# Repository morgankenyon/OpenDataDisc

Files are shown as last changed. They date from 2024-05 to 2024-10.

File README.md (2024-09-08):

# OpenDataDisc

An open platform that allows disc golfers to collect their throw statistics.

> Your throw, your data, your platform.

## Pics

> Putter Dev Board
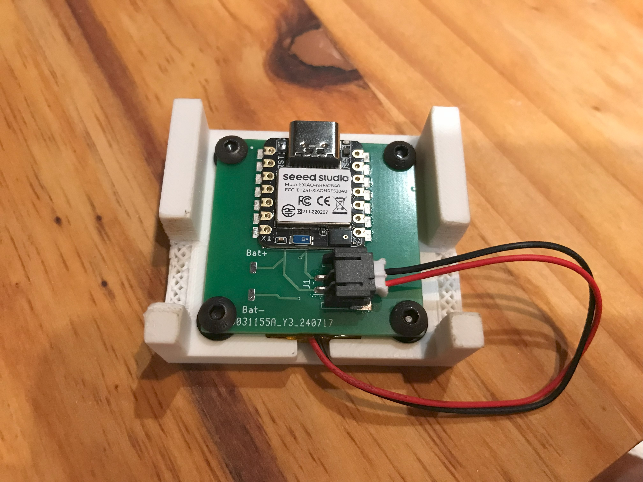
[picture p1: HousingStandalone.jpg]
OpenDataDisc Housing


> Putter Board Mounted On Disc
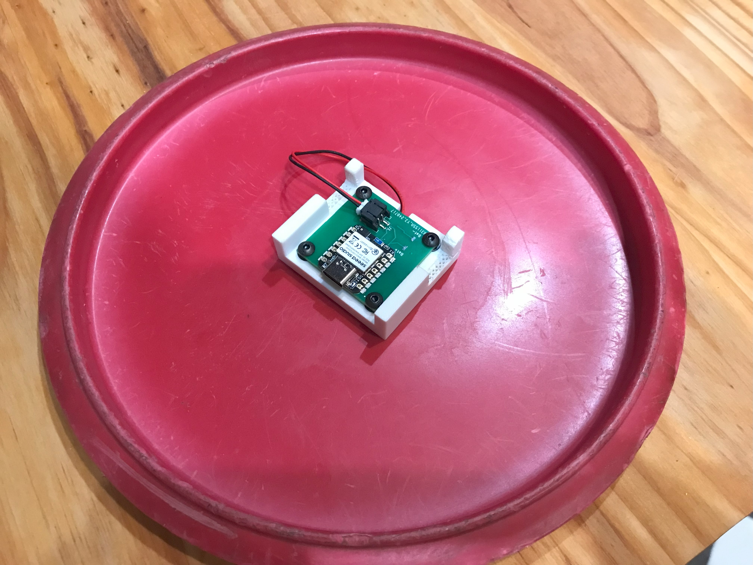
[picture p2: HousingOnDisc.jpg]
OpenDataDisc On Disc


I'm documentating my process over on my [youtube channel](https://www.youtube.com/@BlenderDiscGolf).

## Disc Golf + Analytics

I'd love the ablity to track and measure my disc golf throws without spending tons of money.

* Would it be easier to buy one of the currently available products? Probably.
* What's the likelihood this project never completes its goal? Higher than 0.

So why I am doing it? I'm a sucker for starting something new, I'm a software developer, have started playing disc golf and wanted a project to combine those 2.

Will that mix actually produce something usable? No idea.

## Current Project Phase

Phase: Putter version

As shown in the pics above, I have a putter dev board that I'm just starting to use to measure statistics of putts.

Putts are easier to measure due to low speeds and rpms.

## Project Phases (Somewhat flexible now)

* Getting to know hardware
  * Buying the hardware I think I need.
  * Hooking everything up.
  * Getting data flowing between microcontroller and computer.
  * Getting some basic calculations working
* Putter version (current phase)
  * Putts have slow RPMs and low Gs
    * These values are much easier to measure and test.
    * Hardware is also cheaper.
    * Will probably be using as many off the shelf parts as possible. (Nothing really custom designed)
  * Create a developer kit that can be used for putters.
    * Not something that would probably be widely available, but might create some dev kits for technical people wanting to help.
  * Need some hardware to confirm the sensor values.
    * Speed gun, high speed camera, etc
  * Most R&D on this project will be based on this platform.
* Alpha Driver Disc
  * To develop something to track high speed throws, will probably need:
    * Custom hardware
    * Beefed up software
    * More expensive testing equipment
* Beta Driver Disc
  * Create a more refined alpha setup
  * Any problems I encountered in the Alpha disc can be changed here
* Driver Disc
  * First proper product release
  * Should be easy for non technical people to setup and use
  * Lots of polish will need to happen before this is ready

## Repo Layout

This repo holds both [hardware](./hardware/README.md) and [software](./software/README.md) for the OpenDataDisc project. As this project is still in it's early phase, there's no instructions on how to build your own and run on your own computers. 

That information will come as the project progresses.

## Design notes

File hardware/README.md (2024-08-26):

# OpenDataDisc Hardware

Current status: Attempting to build a putter version. Something that can track low G and low rotation throws.

## Hardware Components

Currently I'm using the following:
* Brains - a [Xiao NRF52 Sense](https://www.seeedstudio.com/Seeed-XIAO-BLE-Sense-nRF52840-p-5253.html)
  * Earlier I used an esp32 microcontroller, but since I didn't need wifi moved to something that fit my requirements and will have longer battery life.
  * This board includes an IMU, USB and LiIon charging circuits built in
* Power - exploring this [110 mAh LiIon battery](https://www.mouser.com/ProductDetail/SparkFun/PRT-13853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), still in the early phases of testing this.
* Casing - 3d printed housing.
  * Currently the files needed to print yourself one are located in [02_putter_housing](./examples/02_putter_housing/).

## DIY Instructions

TBD - right now nothing is integrated. Further instructions will follow as project progresses.

## Examples

The example folder currently contains work that in progress. As hardware designs finalize and are ready for other people to use/build themselves. They will get promoted from the examples folder to this folder.

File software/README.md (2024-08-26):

# OpenDataDisc Software

This folder holds all relevant software for the OpenDataDisc project. Software is split into 2 different sub projects:

* client - .NET based project that runs on a Windows PC. Receives telemetry about the disc from the microcontroller and displays it to the user.
* microcontroller - attached to the disc and is responsible for gathering data about the discs acceleration and movement. Sends that information to the client.

## Current Architectural Guidelines

* Have microcontroller code be as simple as possible.
  * Professionally I'm a .NET developer, I'm more comfortable programming in C#. 
  * I don't want the microcontroller code to get too complex.
* Microcontroller sends raw data to the client
  * Currently the microcontroller does not do any calculations of it's own.
  * It sends pulls in data from sensors and sends to client.
* Client handles all complex calculations
  * Any calculations needed for throws happens on the client.

## How to Run

TBD

Right now the limiting factor in trying this yourself is hardware. I'm still building out a putter version, so until that's at a point where people can copy it there's really no sense it getting this running.

## Examples

In the examples folder are numerous attempts I had to get certain portions of this project running individually. (Can I connect to bluetooth, can I read accelerometer values, can I create a simple Avalonia application). There's not much value in them now.

Our current `/client` and `/microcontroller` code started as examples and were promoted as they became ready.

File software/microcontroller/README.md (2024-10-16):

# Microcontroller

This project uses a [XIAO nRF52840 Sense](https://www.seeedstudio.com/Seeed-XIAO-BLE-Sense-nRF52840-p-5253.html) as the brains.

It's main purpose is to establish a bluetooth connection between itself and the client, then send over accelerometer and gyro sensor readings.

## Local Project Setup

* Install nRF Connect locally
  * Here is a YouTube playlist demonstrating how to do that.
  * https://www.youtube.com/watch?v=EAJdOqsL9m8&list=PLx_tBuQ_KSqEt7NK-H7Lu78lT2OijwIMl
  * I installed the latest versoin at the time (v2.7.0)
* Create build folder
  * By default, the `/build` folder of an nRF Connect project is not checked into git.
    * This is the default right now, not sure if it should change?
  * Using the nRF Connect Plugin, add a new build configuration, target the proper board.
  * nRF 52840 Dev Kit:
  targetting dev kit
    * I used this board during early development
  * XIAO nRF52840 Sense:
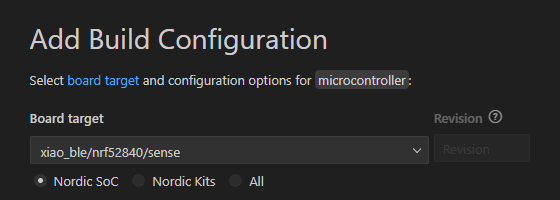
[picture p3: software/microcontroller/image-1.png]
targetting Xiao Sense board
  
  * Just accept the defaults for everything else.
* Build and flash using the plugin
  * Using the nRF Connect Plugin, build and flash the application.
  * You can use the "Connected Devices" area to view the serial monitor if needed.

## Issues and TODOs

None at the moment

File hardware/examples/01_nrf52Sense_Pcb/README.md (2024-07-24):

# NRF52 Sense PCB Design

After watching [this youtube video](https://www.youtube.com/watch?v=2vHB8AUQKWM), it made the point that if I am not planning on using Wifi, the esp32 is a bit overkill. I can reduce my power/battery requirements by picking another board.

So I landed on the NRF52 microcontroller. I specifically have bought a [Seeed Studio XIAO nRF52840 (Sense)](https://wiki.seeedstudio.com/XIAO_BLE/).

This experiment is an attempt to design a PCB that I can attach the dev board to, to one day put it on a disc.

Using a M3 mouting hole on the PCB. Based on Reddit below.

M3 screws have a Major Diameter of 3.0 mm, I made the mounting holes on my PCB 3.1 mm.

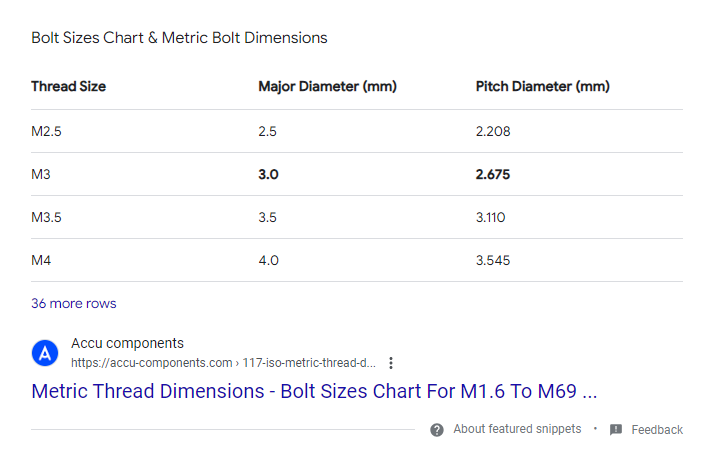
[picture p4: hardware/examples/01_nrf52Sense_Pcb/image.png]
screw mounting sizes


## Resources

* Mounting hole diameter - https://www.reddit.com/r/AskElectronics/comments/uet1u9/comment/i6qwwx0/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
* Generating Gerber Files from Kica - https://www.pcbway.com/helpcenter/technical_support/Generate_Gerber_file_from_Kicad.html

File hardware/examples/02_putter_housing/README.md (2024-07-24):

# Putter Housing (3d Print)

After creating the PCB in example 1, I needed a housing to assemble everything together.

## Tinkercad Design

I have designed the following 3d printed housing:

Tinkercad link: https://www.tinkercad.com/things/eYMJKqX6BG7-incredible-lappi/edit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

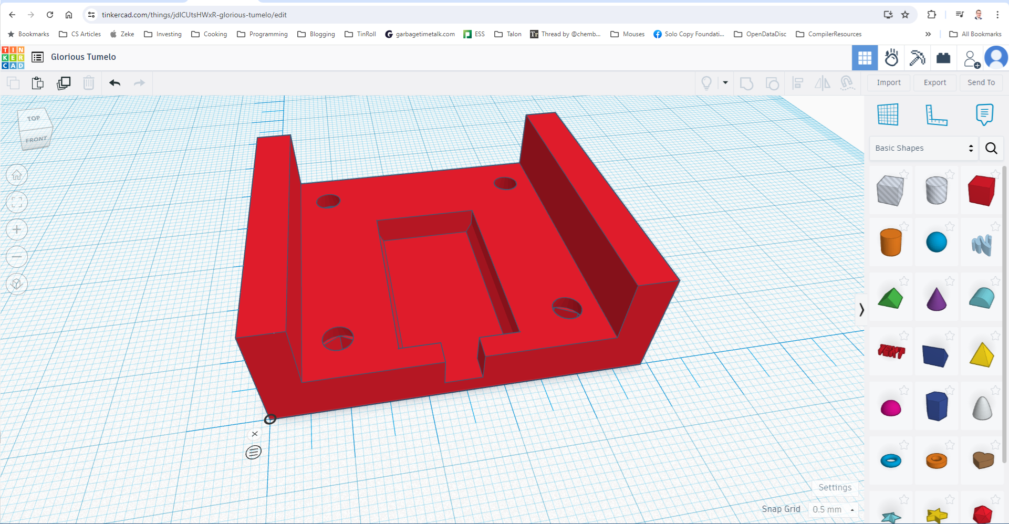
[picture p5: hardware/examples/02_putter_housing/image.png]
putter 3d design


It has 4 screw holes to attach the PCB, a well for the battery and 2 spacers to ensure nothing damages the circuit board.

The 3d design is contained in the [Putter Housing v2.zip](./Putter%20Housing%20v2.zip) file for anyone interested in making their own.

## Resources

* Metric Nut Dimensions - https://amesweb.info/Fasteners/Nut/Metric-Hex-Nut-Sizes-Dimensions-Chart.aspx
* M3 screw kit I bought - https://www.amazon.com/gp/product/B0C8HV5C3N/ref=ppx_yo_dt_b_asin_title_o00_s00?ie=UTF8&psc=1

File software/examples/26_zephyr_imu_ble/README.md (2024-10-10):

# Sending IMU Data Over Bluetooth

In my previous example I was able to pull both the Accelerometer and Gyro data at once.

Now I want to write code that will allow me to send that data over bluetooth to my host machine.

I'll basically be combining code from example 25 and example2/ble_test.

## My goals

1. Send IMU data over to my host machine
2. Allow writing of more than 23 bytes (by default a BLE notify message is limited to 23 bytes)
3. Save the IMU data into the SQLite database.

Todo:
* Determine how to check if bluetooth device is connected before trying to send any notify messages

The new config lines I added to bump up the bluetooth message size.
```
CONFIG_BT_BUF_ACL_RX_SIZE=502
CONFIG_BT_L2CAP_TX_MTU=498
```
## Accomplishment

I'm able to send over about 60 bytes in one bluetooth message, then my C# client can parse that and store it in my SQLite database!!

Let's go!

## Issues

* Building C strings in zephyr
  * https://stackoverflow.com/questions/76546266/float-to-string-in-c-using-nrf-mcu-and-zephyr
* Upping bluetooth byte in zephyr
  * https://devzone.nordicsemi.com/f/nordic-q-a/81860/set-mtu-size-in-zephyr/340755
  * https://lists.zephyrproject.org/g/users/topic/sending_notification_with_mtu/16761407

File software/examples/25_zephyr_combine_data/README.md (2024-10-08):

# Combining Sensor Data

In my previous example I was able to get both the Accelerometer and Gyro data. I made one call to the registers for each data type, 1 for acc and 1 for gyro.

Instead I want to make 1 call and get back all data points.

LSM6DS3 Data Sheet - https://content.arduino.cc/assets/st_imu_lsm6ds3_datasheet.pdf

## My goals

1. Load all data necessary from sensor in one call to the IMU
2. Print that information to the screen.

## Accomplishment

I was able to get both data sets in one interaction with the IMU
```
56000: Acc - X: -0.004514, Y: -0.087108, Z: 0.979538
56000: Gyro - X: 2.598750, Y: -3.508750, Z: -3.710000
56500: Acc - X: -0.048068, Y: -0.032452, Z: 1.012478
56500: Gyro - X: 2.432500, Y: -3.815000, Z: -3.963750
57000: Acc - X: -0.050020, Y: -0.049166, Z: 1.023702
57000: Gyro - X: 2.380000, Y: -3.902500, Z: -4.121250
57500: Acc - X: -0.043798, Y: -0.057340, Z: 1.016504
57500: Gyro - X: 2.572500, Y: -3.876250, Z: -3.902500
58000: Acc - X: -0.007808, Y: -0.050752, Z: 0.982954
58000: Gyro - X: 2.546250, Y: -3.850000, Z: -3.718750
```

## Wiring

Same setup as before, connecting SA0 to ground to have address 0x6A.

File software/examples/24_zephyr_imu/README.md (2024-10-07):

# Zephyr & IMU

After using the temperature sensor, now I want to try to use the Accelerometer and Gyro sensors.

Using this library as a starting point and reference: https://github.com/Seeed-Studio/Seeed_Arduino_LSM6DS3

LSM6DS3 Data Sheet - https://content.arduino.cc/assets/st_imu_lsm6ds3_datasheet.pdf

## My goals

1. Allow easy selection and configuration of Accelerometer and Gyro
2. Provide method to pull data from the accelerometer and gyro
3. Print that data to the screen

### Accelerometer Data

The output of the accelerometer data
```
0: X: -0.018666, Y: -0.106994, Z: 0.979538
1: X: -0.037210, Y: -0.066490, Z: 1.007598
2: X: -0.025498, Y: -0.101260, Z: 0.997594
3: X: -0.050630, Y: -0.120048, Z: 0.977586
4: X: -0.031964, Y: -0.065758, Z: 1.005036
```

### Gyro Data

The output of the gyro data

```
0: Gyro - X: 2.310000, Y: -3.990000, Z: -3.780000
1: Gyro - X: 2.450000, Y: -3.710000, Z: -3.920000
2: Gyro - X: 2.520000, Y: -3.850000, Z: -4.200000
3: Gyro - X: 2.520000, Y: -3.850000, Z: -3.850000
4: Gyro - X: 2.520000, Y: -3.850000, Z: -3.990000
5: Gyro - X: 1.960000, Y: -3.850000, Z: -4.130000
6: Gyro - X: 2.380000, Y: -4.340000, Z: -3.850000
7: Gyro - X: 1.820000, Y: -3.990000, Z: -3.850000
8: Gyro - X: 2.310000, Y: -4.200000, Z: -4.060000
9: Gyro - X: 2.240000, Y: -4.060000, Z: -3.920000
```

If I remember correctly I still need to calibrate these values. So this is a stationary and I'll need to average values out so it gets close to zero.

### Combined Data Output

The combined data output:

```
0: Acc - X: -0.053924, Y: -0.034770, Z: 1.000522
0: Gyro - X: 2.485000, Y: -3.701250, Z: -4.331250
1: Acc - X: -0.013298, Y: -0.090524, Z: 0.975634
1: Gyro - X: 2.572500, Y: -3.797500, Z: -3.797500
2: Acc - X: -0.019032, Y: -0.066246, Z: 0.979416
2: Gyro - X: 2.266250, Y: -3.815000, Z: -3.517500
3: Acc - X: -0.049776, Y: -0.045994, Z: 1.015528
3: Gyro - X: 1.863750, Y: -3.543750, Z: -3.482500
4: Acc - X: -0.042822, Y: -0.047214, Z: 1.004792
4: Gyro - X: 2.345000, Y: -3.762500, Z: -3.815000
5: Acc - X: -0.015372, Y: -0.090890, Z: 0.987102
5: Gyro - X: 2.397500, Y: -3.570000, Z: -3.535000
```

## Wiring

Same setup as before, connecting SA0 to ground to have address 0x6A.

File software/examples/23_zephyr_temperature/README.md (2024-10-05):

# Zephyr Temperature Sensor Tests

My Xiao Sense has a LSM6DS3 IMU built into it.

Previously I was using projectIO to interface with my board. Now that I've moved over to Zephyr, it does not have builtin support for the LSM6DS3.

So I'm attempting to write some code to allow me to pull data from my IMU. I'm going to start with reading from the temperature sensor on the IMU.

LSM6DS3 Data Sheet - https://content.arduino.cc/assets/st_imu_lsm6ds3_datasheet.pdf

While I eventually want to use my Xiao Sense with the IMU, right now I am using the nrf52840-dev-kit for this example.

## Wiring Up My Sensor

I'm using the default i2c nodes on the dev board. For the nrf52840-dev-kit, using the device tree viewer that resulted in this configuration:

```javascript
	i2c0_default: i2c0_default {
		group1 {
			psels = <NRF_PSEL(TWIM_SDA, 0, 26)>,
				<NRF_PSEL(TWIM_SCL, 0, 27)>;
		};
	};
```

SDA = 26
SCL = 27
Then GND and 3v3 connections.

I'm also running ground to the SA0 pin, since the SA0 controls what address the device is reachable at.

## Issues

* fatal error: device.h: No such file or directory
  * Changing my import from `#include <device.h>` to `#include <zephyr/device.h>` fixed it for me.
  * Apparently Zephyr changed how their files were referenced lately: https://stackoverflow.com/a/75943320/1352766
* 'i2c0' undeclared here (not in a function)
  * This was received when trying to define the i2c node: `#define I2C_NODE        DT_NODELABEL(i2c0)`
  * Referencing the device tree:
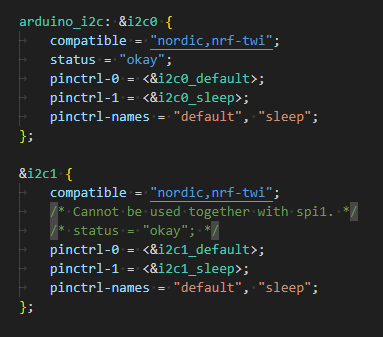
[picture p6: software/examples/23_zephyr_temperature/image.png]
devicetree values

  * `i2c0` didn't seem to be the proper name of that i2c node. I could use either `arduino_i2c` or `i2c1`.
  * Moving to `arduino_i2c` resulted in a successful build for me locally.
* `CONFIG_NEWLIB_LIBC_FLOAT_PRINTF was assigned the value y, but got the value n. Missing dependencies: NEWLIB_LIBC`
  * I removed this from my config file, never really dug into why it was given me an issue
* `i2c_write` fails with a -5 error
  * From this page: https://software-dl.ti.com/simplelink/esd/simplelink_cc13x2_26x2_sdk/5.20.00.52/exports/docs/drivers/doxygen/html/group___i2_c___s_t_a_t_u_s.html
  * -5 = I2C_STATUS_ADDR_NACK (I2C slave address not acknowledged.)
  * confirmed the SA0 pin is connected to ground to try to ensure the i2c device is at memory address 0x6A
  * I probably need to scan through all addresses to see if it shows up anywhere else.
  * Turns out it as at memory address 0x6B for some reason. I'll try to debug further.
memory_addresses
* `read temperature: *float*`
  * Could not print a float out properly.
  * Set this in the `prj.conf` file:
    * `CONFIG_CBPRINTF_FP_SUPPORT=y`
    * It gave this warning though: `Build the cbprintf utility function with support for floating point format specifiers. Selecting this increases stack size requirements slightly, but increases code size significantly.`
  * So apparently enabling float printing has it's drawbacks
  * Since I'm in debug mode it's fine.
* The only temperature value it's printing is 77 F.
  * The IMU might be in test mode.
  * I needed to configure both my Gyro and Accelerometer settings.
  * I did this by writing something to both control registers
    * acc - LSM6DS3_ACC_GYRO_CTRL1_XL
    * gyro - LSM6DS3_ACC_GYRO_CTRL2_G
* Then after that, it started printing out values but was not calibrated.
  * So I had to measure the temperature, compare against an actual temperature gauge, and calculate how many degrees it was off.
  * Mine was off by 16 degrees.
  * The datasheet says the temperature offset would be about +-15 C, which mine is right inline with that.
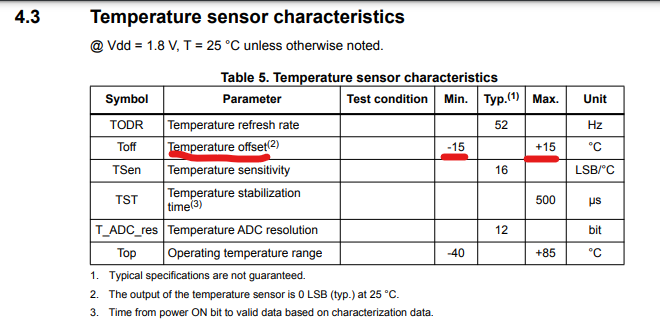
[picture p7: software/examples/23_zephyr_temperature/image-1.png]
temperature data sheet info


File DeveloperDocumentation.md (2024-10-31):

# Developer Documentation

This file contains all technical documentation for this project.

## Microcontroller

TBD

## Avalonia Client

### Database Conventions

* snake_case for all table names, column names and migration names

### Database Migrations

This project uses SQLite to save data coming from disc. The schema of this database is managed by the [DataSchemaService](./software/client/OpenDataDisc.Services/DataSchemaService.cs).

To create a new migration:

* Create a new entry into the `Migration` enum.
  * Ensure it's value is N + 1, where N is the current highest enum value.
* Add a new case statement in `MigrateSchema` method.
* Write SQL statement that will complete the migration
  * Wrap it in a transaction
  * Ensure you insert a new record into the migration table
    * Provide a unique name in snake case (all_lower_text_and_no_spaces)
* Update the class instance variable `_latestMigration` to match your new migration

Expected test cases. 

> In any database PR please indicate whether you've manually performed these steps.

* No SQLite database
  * Ensure on startup a new database is created with all former migrations and your new one.
* Just Your Migration
  * SQLite database with all former migrations.
  * Ensure on startup your migration is added successfully.
* From Latest Release - Future Test Case
  * Start with database from last official release.
  * Ensure on startup that your migration (and any others added since migration) are completed successfully.
* Schema Update Error Rollback
  * Modify your schema update so it fails.
  * Run and see it error out, ensure that the database schema has not been modified at all.
* Migration Tracking Error Rollback
  * Modify your Migration Tracking sql statement so it fails.
  * Run and see it error out, ensure that the database schema has not been modified at all.

Example for last two test cases:

```sql
BEGIN TRANSACTION;

-- Schema Update
CREATE TABLE migrations (name VARCHAR(50), number INT);

-- Migration Tracking
INSERT INTO migrations (name, number) VALUES ('migration_table', 1);

COMMIT;
```

* This migration has 2 logical parts:
  * Schema Update - schema changes to be made
  * Migration Tracking - adding record into migration table indicating migration was run.

* To test the "Schema Update Error Rollback" test case, change your schema so it fails:
  * `CREATEING TABLE migrations (name VARCHAR(50), number INT);`
  * And ensure rollback is successful
* To test the "Migration Tracking Error Rollback" test case, change the statement so it fails:
  * `INSERTING INTO migrations (name, number) VALUES ('migration_table', 1);`

### Icons

The [Avalonia Docs](https://docs.avaloniaui.net/docs/tutorials/music-store-app/add-and-layout-controls#button-icon) detail how to add new icons to the Avalonia project.

But simply:

* Load the above url
* Find the icon url listed in that page
  * Currently: https://avaloniaui.github.io/icons.html
* Pick an icon
* Copy the `StreamGeometry` tag into the `Icons.axaml`
* Use the `x:Key` wherever is needed.

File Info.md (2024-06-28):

# Info

## MPU 6050 Sensor Info

* 250 deg/s = 131 LSB deg/s
* 500 deg/s = 65.5 LSB deg/s
* 1000 deg/s = 32.8 LSB deg/s
* 2000 deg/s = 16.4 LSB deg/s

https://www.youtube.com/watch?v=yhz3bRQLvBY ~ 4:44 mark

* +/- 2g - 16384 LSB/g
* +/- 4g - 8192 LSB/g
* +/- 8g - 4096 LSB/g
* +/- 16g - 2048 LSB/g

https://www.youtube.com/watch?v=7VW_XVbtu9k ~ 7:53 mark

## Future Sensors

* [High G Single Axis Accelerometer](https://www.sparkfun.com/products/retired/9332)
  * Discontinued, but I could potentially use 2 of these to build a high G sensor.
* [High Performace Gyroscope](https://www.mouser.com/ProductDetail/Analog-Devices/ADXRS649BBGZ?qs=WIvQP4zGanhEKWMUW9AK8A%3D%3D)
  * Maybe combine with above to create my own IMU, idk.
* [200 g sensors](https://www.mouser.com/c/sensors/motion-position-sensors/accelerometers/?acceleration=200%20g)
  * There does seem to be some 200 g sensors that are relatively affordable that I could buy and create my own breadboard for.
* [Replacement for mpu 6050](https://www.mouser.com/ProductDetail/TDK-InvenSense/ICM-42605?qs=gZXFycFWdAO0MPgeewGYjQ%3D%3D)
  * Seems like the mpu 6050 is old

## Battery Info

* Resources
  * https://www.youtube.com/watch?v=vBIE0agqBW0
    * Considerations with UL - https://www.autodesk.com/products/fusion-360/blog/ul-certification-for-electronics-design/
    * A lot of big box stores require UL listings for general safety concerns
    *

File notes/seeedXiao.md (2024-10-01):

# Seeed Xiao

* Battery Burn Out - https://github.com/honvl/Seeed-Xiao-NRF52840-Battery/issues/1
* IMU - LSM6DS3
* LSM6DS3 libraries for zephyr
  * https://github.com/StefJar/zephyr_lsm6ds3_driver
  * https://github.com/iwasz/example-zephyr-module - no license
  * https://devzone.nordicsemi.com/f/nordic-q-a/66230/how-to-add-new-i2c-based-sensor-device-to-ncs-v1-3-0-zephyr-drivers-sensor

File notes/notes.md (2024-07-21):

# Random Notes

## Changes needed/Notes

* New Gyroscope
  * The gyroscope currently being used only supports up to 2,000 deg/s, which is ~333 RPM. Disc golf throws can go upwards of 1500 RPM. So that won't work long term.
  * I found [this gyroscope](https://www.mouser.com/ProductDetail/Analog-Devices/ADXRS649BBGZ?qs=WIvQP4zGanhEKWMUW9AK8A%3D%3D) that supports up to 20,000 deg/s, which is ~3,333 RPM, more than enough. It's just ~$120ish bucks.
* New Accelerometer
  * Also will need a new accelerometer to support up to 150 gs.
  * Might use [this one](https://www.mouser.com/ProductDetail/Analog-Devices/ADXL314WBCPZ-RL?qs=4ASt3YYao0VqiVnUWLAbOQ%3D%3D)
* G forces found in disc golf throws.
  * [Here's a link](https://www.reddit.com/r/discgolf/comments/13fbddc/comment/jjxg0cy/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) stating a throw can generate up to 175 Gs.

## Things to Explore

https://github.com/dotnet-bluetooth-le/dotnet-bluetooth-le/

https://github.com/microsoft/Windows-universal-samples/tree/main/Samples/BluetoothLE

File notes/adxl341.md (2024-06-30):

# ADXL314 3 Axis Accelerometer

Since the MPU 6050 only gose up to 16G, this might be the sensor that I choose to detect higher performance stats.

* Data Sheet - https://www.analog.com/media/en/technical-documentation/data-sheets/adxl314.pdf
* Breakout Board Sheet - https://www.analog.com/media/en/technical-documentation/user-guides/eval-adxl314-ug-2043.pdf
* Quick Start User Guide - https://wiki.analog.com/resources/quick-start/adxl314_quick_start_guide

Code snippets. Not sure if there's an arduino library written for it yet. I have seen a couple for the 313.
* https://docs.arduino.cc/built-in-examples/sensors/ADXL3xx/
* https://forum.arduino.cc/t/throuble-interfacing-with-adxl314-though-spi/1236049
* 314 Library - https://github.com/sparkfun/SparkFun_ADXL313_Arduino_Library
* https://wiki.analog.com/resources/tools-software/linux-drivers/iio-accelerometer/adxl313

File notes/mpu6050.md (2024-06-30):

# Notes on the MPU 6050

Part of this project is trying to understand what the electronics are doing. At some point I'll probably want to create something custom (circuit board, etc), I need to understand the underlying electronics.

Questions:
* How does a breakout board allow easier access to the mpu 6050?
* What is the raw mpu 6050 output?
  * How do analog-to-digital converters make interfacing with the mpu 6050 easier?
* How do analog-to-digital converters digitize the gyroscope and accelerometer outputs?
  * The MPU-60X0 features three 16-bit analog-to-digital converters (ADCs) for digitizing the gyroscope outputs and three 16-bit ADCs for digitizing the accelerometer outputs. 
  * [section 3.1 of source](https://invensense.tdk.com/wp-content/uploads/2015/02/MPU-6000-Datasheet1.pdf)
* Exploring a [breakout board](https://dlnmh9ip6v2uc.cloudfront.net/datasheets/Sensors/IMU/MPU-6050_Breakout%20V11.pdf), what do the following values mean?
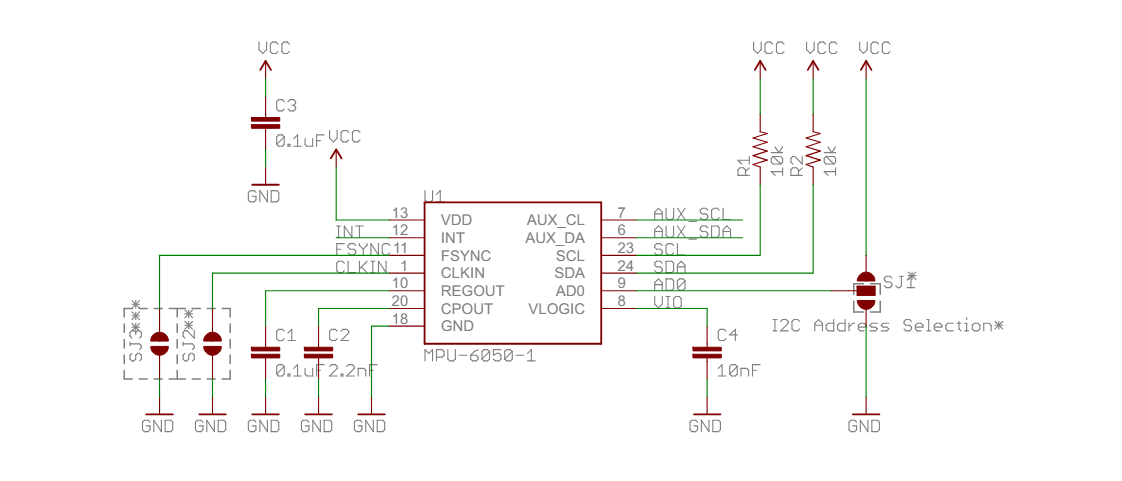
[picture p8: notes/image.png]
breakout board
  
  * VDD
  * INT
  * FSYNC
  * CLKIN
  * REGOUT
  * CPOUT
  * GND
  * AUX_SCL
  * AUX_SDA
  * SCL
  * SDA
  * AD0
  * VLOGIC - Digital I/O supply voltage
    * VLOGIC reference pin is used to set the logic levels of the I2C interface. [ref](https://www.elprocus.com/mpu6050-pin-diagram-circuit-and-applications/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,levels%20of%20the%20I2C%20interface.)
* How can I communicate with the device through registers?
  * "Communication with all registers of the device is performed using either I2C at 400kHz or SPI at 1MHz (MPU-6000 only)." [datasheet](https://invensense.tdk.com/wp-content/uploads/2015/02/MPU-6000-Datasheet1.pdf)
* How to interface with an I2C serial port?
* [Data sheet](https://invensense.tdk.com/wp-content/uploads/2015/02/MPU-6000-Datasheet1.pdf) contains the following information:
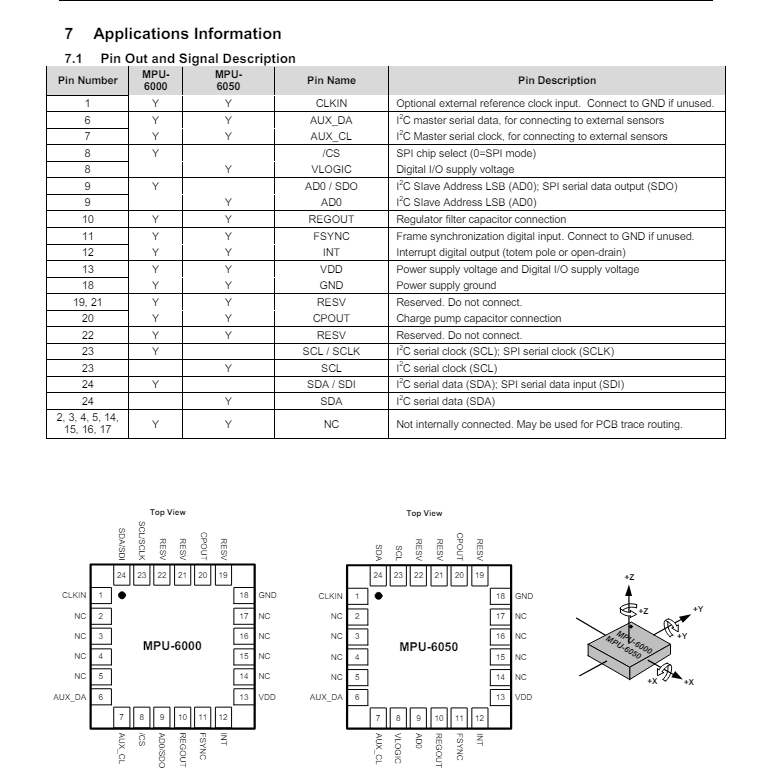
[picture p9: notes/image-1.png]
mpu 6050 datasheet

* A reference to a mpu6050 [breakout board design](https://electronics.stackexchange.com/questions/438719/checking-my-mpu6050-schematic)
* What is the I2C protocol?
* How can I build my own analog-to-digital converters? (16 ADC)
  * https://www.youtube.com/watch?v=CESSBRoHoFs
* Spark fun reference - https://www.sparkfun.com/products/retired/11028
  * Schematic - https://cdn.sparkfun.com/datasheets/Sensors/IMU/Triple_Axis_Accelerometer-Gyro_Breakout_-_MPU-6050_v12.pdf
  * Schematic showing pin numbers for Qwiic connector - https://cdn.sparkfun.com/assets/0/9/6/b/4/Qwiic_BME280_Schematic_attempt2.pdf
    * GND is 1, SCL is 4

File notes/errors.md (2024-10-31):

# Commonly Occurred Errors

## Avalonia Errors

### Statis resource not found

Encountered the following exception:
```
Exception: KeyNotFoundException
Message: Static resource 'm:StateToVisibilityConverter' not found.
Stack Trace:    at Avalonia.Markup.Xaml.MarkupExtensions.StaticResourceExtension.ProvideValue(IServiceProvider serviceProvider)
   at OpenDataDisc.UI.Views.MainWindow.!XamlIlPopulate(IServiceProvider, MainWindow) in C:\dev\OpenDataDisc\software\client\OpenDataDisc.UI\Views/MainWindow.axaml:line 41
   at OpenDataDisc.UI.Views.MainWindow.!XamlIlPopulateTrampoline(MainWindow)
   at OpenDataDisc.UI.Views.MainWindow.InitializeComponent(Boolean loadXaml, Boolean attachDevTools) in C:\dev\OpenDataDisc\software\client\OpenDataDisc.UI\obj\Debug\net8.0-windows10.0.22621.0\Avalonia.Generators\Avalonia.Generators.NameGenerator.AvaloniaNameSourceGenerator\OpenDataDisc.UI.Views.MainWindow.g.cs:line 23
   at OpenDataDisc.UI.Views.MainWindow..ctor() in C:\dev\OpenDataDisc\software\client\OpenDataDisc.UI\Views\MainWindow.axaml.cs:line 12
   at OpenDataDisc.UI.App.OnFrameworkInitializationCompleted() in C:\dev\OpenDataDisc\software\client\OpenDataDisc.UI\App.axaml.cs:line 49
   at Avalonia.AppBuilder.SetupUnsafe()
   at Avalonia.AppBuilder.Setup()
   at Avalonia.AppBuilder.SetupWithLifetime(IApplicationLifetime lifetime)
   at Avalonia.ClassicDesktopStyleApplicationLifetimeExtensions.StartWithClassicDesktopLifetime(AppBuilder builder, String[] args, Action`1 lifetimeBuilder)
   at OpenDataDisc.UI.Program.Main(String[] args) in C:\dev\OpenDataDisc\software\client\OpenDataDisc.UI\Program.cs:line 19
```

I wasn't referencing my converter properly. I fixed this by introducing a `Window.Resources` section to define and import (might not be the proper term) this namespace/object.

```xml
	<Window.Resources>
		<m:StateToVisibilityConverter x:Key="StateToVisibilityConverter" />
	</Window.Resources>
```

## Zephyr Bluetooth

`C:/ncs/v2.7.0/nrf/include/bluetooth/scan.h:223:36: error: 'CONFIG_BT_SCAN_UUID_CNT' undeclared here (not in a function)`

Couldn't fix this issue. Ended up removing the extra code I used for the connect/disconnect bluetooth callbacks.

## Issue Writing Message to Server

In trying to get configuration to work. It's something the client needs to inform the server that is wants to do. I wanted to Write a message to the Server.

When I tried I got the following error:
```
   at InTheHand.Bluetooth.GattCharacteristic.<PlatformWriteValue>d__36.MoveNext()
   at OpenDataDisc.UI.ViewModels.MainWindowViewModel.<ListenToDevice>d__45.MoveNext() in C:\dev\OpenDataDisc\software\client\OpenDataDisc.UI\ViewModels\MainWindowViewModel.cs:line 267
   at System.Threading.Tasks.Task.<>c.<ThrowAsync>b__128_0(Object state)
   at Avalonia.Threading.SendOrPostCallbackDispatcherOperation.InvokeCore()
   at Avalonia.Threading.DispatcherOperation.Execute()
   at Avalonia.Threading.Dispatcher.ExecuteJob(DispatcherOperation job)
   at Avalonia.Threading.Dispatcher.ExecuteJobsCore(Boolean fromExplicitBackgroundProcessingCallback)
   at Avalonia.Threading.Dispatcher.Signaled()
   at Avalonia.Win32.Win32Platform.WndProc(IntPtr hWnd, UInt32 msg, IntPtr wParam, IntPtr lParam)
   at Avalonia.Win32.Interop.UnmanagedMethods.DispatchMessage(MSG& lpmsg)
   at Avalonia.Win32.Win32DispatcherImpl.RunLoop(CancellationToken cancellationToken)
   at Avalonia.Threading.DispatcherFrame.Run(IControlledDispatcherImpl impl)
   at Avalonia.Threading.Dispatcher.PushFrame(DispatcherFrame frame)
   at Avalonia.Threading.Dispatcher.MainLoop(CancellationToken cancellationToken)
   at Avalonia.Controls.ApplicationLifetimes.ClassicDesktopStyleApplicationLifetime.Start(String[] args)
   at Avalonia.ClassicDesktopStyleApplicationLifetimeExtensions.StartWithClassicDesktopLifetime(AppBuilder builder, String[] args, Action`1 lifetimeBuilder)
   at OpenDataDisc.UI.Program.Main(String[] args) in C:\dev\OpenDataDisc\software\client\OpenDataDisc.UI\Program.cs:line 19

```
If I catch the exception:

```csharp
byte[] configureMessage = Encoding.UTF8.GetBytes("configure\n");
try
{

   await chars.WriteValueWithResponseAsync(configureMessage);
}
catch (System.Runtime.InteropServices.COMException comException)
{
   configureMessage = Encoding.ASCII.GetBytes("hello");
}
```

The ComException has an empty error message the following error code:`0x80650003`

Stackoverflow with same error code: https://stackoverflow.com/questions/38804878/uwp-system-runtime-interop-comexception-on-debug-but-system-exception-on-release
Something to try: https://stackoverflow.com/questions/48973287/failed-to-subscribe-to-notification-characteristic-in-bluetooth-low-energy

It ended up being a permissions issue. I was configuring bluetooth in zephyr as such:

```c
BT_GATT_SERVICE_DEFINE(custom_srv,
	BT_GATT_PRIMARY_SERVICE(ODD_SERVICE),
	BT_GATT_CHARACTERISTIC(ODD_SENSOR_CHRC, 
        BT_GATT_CHRC_NOTIFY | BT_GATT_CHRC_WRITE | BT_GATT_CHRC_WRITE_WITHOUT_RESP,
        BT_GATT_PERM_NONE,       //this right here
        NULL,
        on_write,
        NULL),
	BT_GATT_CCC(NULL, BT_GATT_PERM_READ | BT_GATT_PERM_WRITE),
);
```

I changed "BT_GATT_PERM_NONE" => "BT_GATT_PERM_WRITE" and my server was able to receive the message from the client.

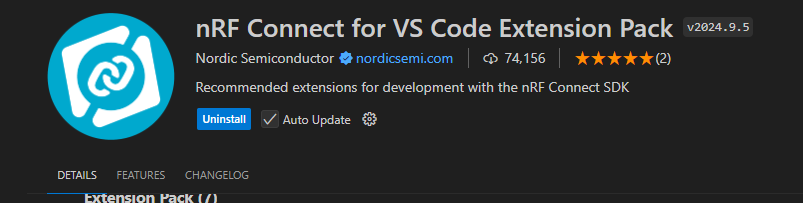
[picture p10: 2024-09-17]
software/examples/20_nrfconnect/image.png

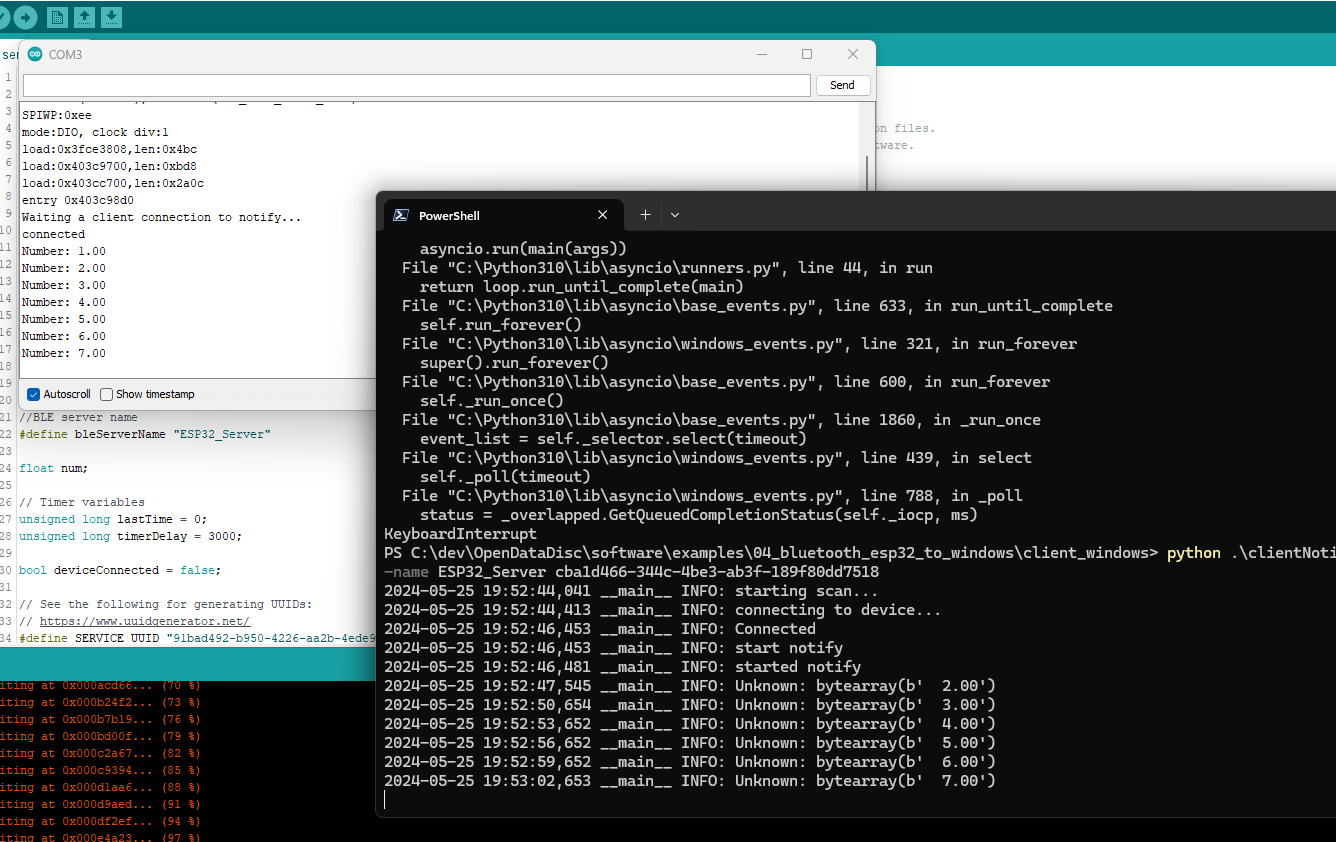
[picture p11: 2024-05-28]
software/examples/04_bluetooth_esp32_to_windows/image.png

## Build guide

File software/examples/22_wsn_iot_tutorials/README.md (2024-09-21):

# WSN & Iot Tutorials

As I'm learning the nrf52840 Dev Kit board, I'm now going to start following this tutorial series: https://www.youtube.com/watch?v=QTtLZIPcYfM&list=PLoKOKJqgqHs9mReagSVnB8FAQBJuRMCEt&index=1&t=14s

It goes through a lot of things about the board and will help me gain a basic understanding.

## Video #1 - Installing

* I downloaded the [nRF Connect for Desktop](https://www.nordicsemi.com/Products/Development-tools/nRF-Connect-for-Desktop/Download?lang=en#infotabs) tool.
  * Currently on v5.0.2.
  * I proceeded to download the Bluetooth Low Energy testing application
  * I also installed the "Toolchain Manager".

## Video #2 - GPIOs, Leds and DeviceTree

Have some examples in `my_second_blinky`, mostly over my head thought.

## Video #3 - Battery Service

https://www.youtube.com/watch?v=CVFbqMMiX2U

Changing over to the bluetooth videos as they are more appropriate for what I want to do.

Code exists in the `ble_battery_service` project.

## Video #4 - Environmental Sensing Service

https://www.youtube.com/watch?v=D9cv3_Z8qwg

Code exists in the `ble_ess` project.

## Video #5 - Custom Service

https://www.youtube.com/watch?v=o-NECS2TN94

Code exists in the `ble_custom_service` project.

## Trying to get notify to work

Code exists in the `ble_test` project.

Links for getting notify to work:

* https://devzone.nordicsemi.com/f/nordic-q-a/94008/custom-notification-characteristic-not-updating
* https://devzone.nordicsemi.com/guides/nrf-connect-sdk-guides/b/software/posts/building-a-ble-application-on-ncs-comparing-and-contrasting-to-softdevice-based-ble-app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

### Issues

I encountered an issue where my Visual studio Code build just reran and reran. I think this was due to my copying projects and paths being pointed to wrong places.

I deleted my build folder and regenerated it via the nRF Connect VS Code Extension and it worked as expected.

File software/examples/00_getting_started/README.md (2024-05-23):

# Getting Started with Esp32

I bought this microcontroller: https://www.mouser.com/ProductDetail/Espressif-Systems/ESP32-S3-DevKitM-1-N8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

> ESP32-S3-DevKitC-1-N8 - WiFi Development Tools - 802.11 ESP32-S3 General-Purpose Development Board, ESP32-S3-WROOM-1-N8, with Pin Header

I had the following problems in getting a blink example working:

* Needed to install esp32 for arduino IDE
  * I googled for how to do this
* Figured out which board to select in the Arduino IDE
  * Went with "ESP32S3 Dev Module"
* Figure out which port to use
  * This microcontroller comes with 2 usb ports (labeled UART and USB).
  * Did some googling, it seems like the UART port is more the debugging one. The USB port is more for mimicing a USB device, if you were trying to do that.
  * So using UART port.
* I needed to use a good usb cable
  * Some usb cables only do power, some do data and power.
  * I was using one, my computer wouldn't recognize it, I tried a better one and my port popped right up.
* Then I needed to download the driver for USB to UART bridge
  * Windows wouldn't automatically recognize my esp32, and wouldn't download the driver automatically.
  * After googling I found a driver on Silicon Labs website. I choose the "Windows Driver" instead of the "Universal Windows Driver"
* Then finally got it to recognize my microcontroller:
device manager
  * Previously it was under the "Other devices" category and had an error saying it couldn't find the driver
* Now I can upload the Arduino IDE builtin Blink sketch (located at File > Examples > 01.Basic > Blink) and run on the esp32!

First example down, now on to an accelerometer!

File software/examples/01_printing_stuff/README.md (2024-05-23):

# Send Messages from ESP 32 to Computer

I couldn't get messages working initially, I think my issue came down to a incorrect baud rate.

I believe these 2 options need to align:

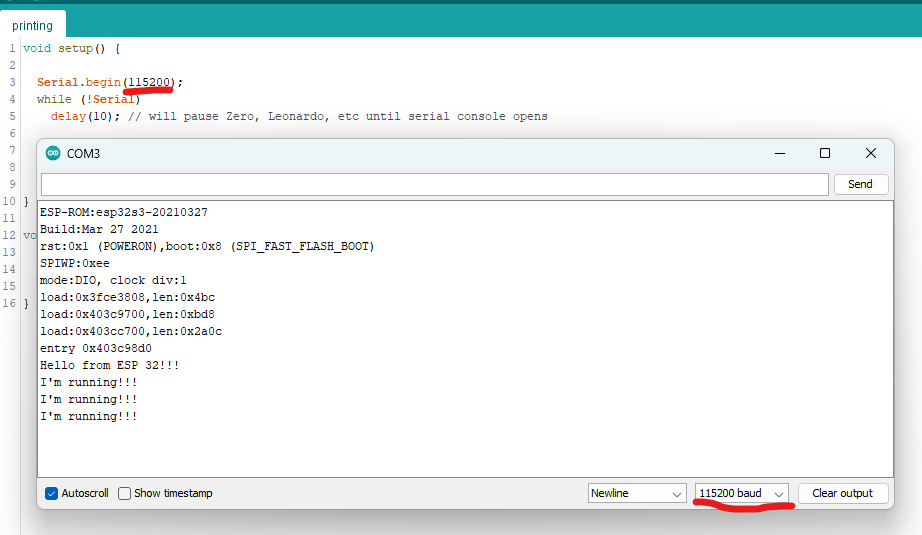
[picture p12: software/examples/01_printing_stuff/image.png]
ide with serial monitor


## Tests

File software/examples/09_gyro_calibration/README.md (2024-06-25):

# Sensor Calibration

I am currently using a Accelerometer + Gyro sensor to track movements. The only problem is out of the box the sensor isn't measuring correctly.

This example will be based mainly off of [this video](https://www.youtube.com/watch?v=Yh6mYF3VdFQ).

## Basic Idea

* Take a lot of static measurements of my sensor.
* Then take averages of those measurements
* Use those averages calibrate my gyroscope

## Hardware Setup

Using the basic accelerometer setup found in [example2](../02_accelerometer/)

## Software Setup

### Esp32

* Upload to board
  * `pio run --target upload`

### Windows Client

To run: `dotnet build; dotnet run`.

This connects to the esp32, pulls in a bunch of sensor data, then outputs a json file containing the gyro calibration values (x, y, z).

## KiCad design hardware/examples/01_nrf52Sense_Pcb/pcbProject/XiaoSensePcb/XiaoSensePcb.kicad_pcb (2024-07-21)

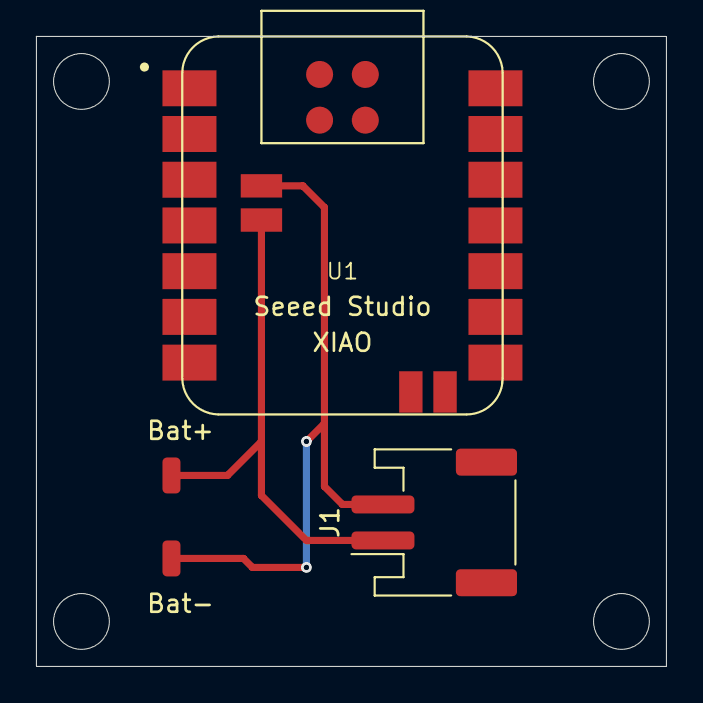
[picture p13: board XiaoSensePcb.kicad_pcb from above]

Board: 2 copper layers, 35.0 x 35.0 mm, 4 parts (0 on the bottom side), 2 nets.

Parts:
Bat+: SolderWirePad_1x01_SMD_1x2mm
Bat-: SolderWirePad_1x01_SMD_1x2mm
J1: Conn_01x02; JST_PH_S2B-PH-SM4-TB_1x02-1MP_P2.00mm_Horizontal
U1: Seeed Studio XIAO nRF52840; XIAO-nRF52840-Sense-14P-2.54-21X17.8MM

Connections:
unnamed: Bat+.1, J1.1, U1.22 (BAT+)
unnamed: Bat-.1, J1.2, U1.21 (BAT-)

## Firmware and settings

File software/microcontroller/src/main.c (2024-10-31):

#include <zephyr/kernel.h>
#include <zephyr/device.h>
#include <zephyr/devicetree.h>
#include <zephyr/drivers/i2c.h>
#include <zephyr/drivers/gpio.h>

#include <inttypes.h>
#include <stdio.h>

//bluetooth imports
#include <zephyr/bluetooth/bluetooth.h>
#include <zephyr/bluetooth/conn.h>
#include <zephyr/bluetooth/gatt.h>
#include <zephyr/bluetooth/uuid.h>

//General Macros and variables
#define THROW_SLEEP_TIME_MS                 100
#define CONFIG_SLEEP_TIME_MS                10
#define UNCONNECTED_SLEEP_TIME_MS           4000
#define I2C_NODE        DT_NODELABEL(arduino_i2c)
static const struct device *i2c_dev = DEVICE_DT_GET(I2C_NODE);

static uint8_t acc_buffer[6];

/****************** Device specific Macros  ******************/
//These addresses needs to be associated with the input to the SA0 pin
#define IMU_ADDRESS 0x6A            //imu address when SA0 connected to ground
//#define IMU_ADDRESS 0x6B          //imu address when SA0 connected to VDD

//falling register naming convetion located here: https://github.com/Seeed-Studio/Seeed_Arduino_LSM6DS3/blob/master/LSM6DS3.h
//WHO_AM_I
#define LSM6DS3_ACC_GYRO_WHO_AM_I_REG       0X0F
//accelerometer control configuration register
#define LSM6DS3_ACC_GYRO_CTRL1_XL  			0X10
//gyro control configuration register
#define LSM6DS3_ACC_GYRO_CTRL2_G  			0X11
//rounding and sensor test status
#define LSM6DS3_ACC_GYRO_CTRL5_C            0X14
//controle register
#define LSM6DS3_ACC_GYRO_CTRL10_C           0X19
//temperature registers
#define LSM6DS3_ACC_GYRO_OUT_TEMP_L         0x20
#define LSM6DS3_ACC_GYRO_OUT_TEMP_H         0x21
//gyroscope registers
#define LSM6DS3_ACC_GYRO_OUTX_L_G           0X22
#define LSM6DS3_ACC_GYRO_OUTX_H_G           0X23
#define LSM6DS3_ACC_GYRO_OUTY_L_G           0X24
#define LSM6DS3_ACC_GYRO_OUTY_H_G           0X25
#define LSM6DS3_ACC_GYRO_OUTZ_L_G           0X26
#define LSM6DS3_ACC_GYRO_OUTZ_H_G           0X27
//accelerometer registers
#define LSM6DS3_ACC_GYRO_OUTX_L_XL          0X28
#define LSM6DS3_ACC_GYRO_OUTX_H_XL          0X29
#define LSM6DS3_ACC_GYRO_OUTY_L_XL          0X2A
#define LSM6DS3_ACC_GYRO_OUTY_H_XL          0X2B
#define LSM6DS3_ACC_GYRO_OUTZ_L_XL          0X2C
#define LSM6DS3_ACC_GYRO_OUTZ_H_XL          0X2D


/****************** Bluetooth Macros  ******************/
// UUID of the custom service
#define ODD_SERV_VAL BT_UUID_128_ENCODE(0x900e9509, 0xa0b2, 0x4d89, 0x9bb6, 0xb5e011e758a0)
#define ODD_SERVICE BT_UUID_DECLARE_128(ODD_SERV_VAL)

// UUID of the custom temperature characteristic
#define ODD_SENSOR_CHRC_VAL BT_UUID_128_ENCODE(0x6ef4cd45, 0x7223, 0x43b2, 0xb5c9, 0xd13410b494a5)
#define ODD_SENSOR_CHRC BT_UUID_DECLARE_128(ODD_SENSOR_CHRC_VAL)


/****************** Structs and enums  ******************/
typedef enum AccelerometerSampleRate {
    ACC_SR_POWER_DOWN      = 0x00,
    ACC_SR_13Hz            = 0x10,
    ACC_SR_26Hz            = 0x20,
    ACC_SR_52Hz            = 0x30,
    ACC_SR_104Hz           = 0x40,
    ACC_SR_208Hz           = 0x50,
    ACC_SR_416Hz           = 0x60,
    ACC_SR_833Hz           = 0x70,
    ACC_SR_1660Hz          = 0x80,
    ACC_SR_3330Hz          = 0x90,
    ACC_SR_6660Hz          = 0xA0,
    ACC_SR_13330Hz         = 0xB0,
} AccelerometerSampleRate;

typedef enum AccelerometerScale {
    ACC_SCALE_2G              = 0x00,
    ACC_SCALE_16G             = 0x04,
    ACC_SCALE_4G              = 0x08,
    ACC_SCALE_8G              = 0x0C,
} AccelerometerScale;

typedef enum AccelerometerBandwidth {
    ACC_BANDWIDTH_400HZ     = 0x00,
    ACC_BANDWIDTH_200HZ     = 0x01,
    ACC_BANDWIDTH_100HZ     = 0x02,
    ACC_BANDWIDTH_50HZ      = 0x03,
} AccelerometerBandwidth;

typedef enum GyroSampleRate {
    GYRO_SR_POWER_DOWN     = 0x00,
    GYRO_SR_13Hz           = 0x10,
    GYRO_SR_26Hz           = 0x20,
    GYRO_SR_52Hz           = 0x30,
    GYRO_SR_104Hz          = 0x40,
    GYRO_SR_208Hz          = 0x50,
    GYRO_SR_416Hz          = 0x60,
    GYRO_SR_833Hz          = 0x70,
    GYRO_SR_1660Hz         = 0x80,
} GyroSampleRate;

typedef enum GyroScale {
    GYRO_SCALE_250dps       = 0x00,
    GYRO_SCALE_500dps       = 0x04,
    GYRO_SCALE_1000dps      = 0x08,
    GYRO_SCALE_2000dps      = 0x0C,
} GyroScale;

typedef enum GyroFullScale {
    GYRO_FULLSCALE_125dps_DISABLED      = 0x00,
    GYRO_FULLSCALE_125dps_ENABLED       = 0x02,
} GyroFullScale;

typedef enum OperationMode {
    THROW           = 0x00,
    CONFIG          = 0x02
} OperationMode;

typedef struct IMUSettings
{
    AccelerometerSampleRate accSampleRate;
    AccelerometerScale accScale;
    AccelerometerBandwidth accBandwidth;
    GyroSampleRate gyroSampleRate;
    GyroScale gyroScale;
    GyroFullScale gyroFullScale;
} IMUSettings;

typedef struct AcceloremeterData
{
    float AccX;
    float AccY;
    float AccZ;
} AcceloremeterData;

typedef struct GyroData
{
    float GyroX;
    float GyroY;
    float GyroZ;
} GyroData;

typedef struct IMUData
{
    AcceloremeterData aData;
    GyroData gData;
    uint32_t cycleCount;
} IMUData;

enum OperationMode operation_mode;


/************* Bluetooth Info **************/
volatile bool ble_ready=false;
volatile bool ble_connected=false;

static const struct bt_data ad[] = 
{
    BT_DATA_BYTES(BT_DATA_FLAGS, (BT_LE_AD_GENERAL | BT_LE_AD_NO_BREDR)),
    BT_DATA_BYTES(BT_DATA_UUID128_ALL, ODD_SERV_VAL)
};


//used to read messages written to the server from the client
static ssize_t on_write(struct bt_conn *conn, const struct bt_gatt_attr *attr,
                        const void *buf, uint16_t len, uint16_t offset, uint8_t flags)
{
    char received_data[100];  // Adjust size based on your expected data length

    printk("In on_write\n");
    // Ensure the length does not exceed buffer size
    if (len >= sizeof(received_data)) {
        printk("Error: Data too long to fit into buffer\n");
        return BT_GATT_ERR(BT_ATT_ERR_INVALID_ATTRIBUTE_LEN);
    }

    // Copy the incoming bytes to the string buffer and add null termination
    memcpy(received_data, buf, len);
    received_data[len] = '\0';  // Null-terminate the string

    // Print or process the received string
    printk("Received data as string: %s\n", received_data);

    if (strcmp(received_data, "throw") == 0) {
        operation_mode = THROW;
    } else if (strcmp(received_data, "config") == 0) {
        operation_mode = CONFIG;
    } else {
        printk("Received unknown command\n");
    }

    // Return the number of bytes written
    return len;
}

BT_GATT_SERVICE_DEFINE(custom_srv,
	BT_GATT_PRIMARY_SERVICE(ODD_SERVICE),
	BT_GATT_CHARACTERISTIC(ODD_SENSOR_CHRC, 
        BT_GATT_CHRC_NOTIFY | BT_GATT_CHRC_WRITE | BT_GATT_CHRC_WRITE_WITHOUT_RESP,
        BT_GATT_PERM_WRITE,
        NULL,
        on_write,
        NULL),
	BT_GATT_CCC(NULL, BT_GATT_PERM_READ | BT_GATT_PERM_WRITE),
);
/********************* Utility Functions  *****************/
/*
 * Gets uptime of system in milliseconds
 * Since Zephyr is an embedded system, can't really get time since epoch
 * For sensor time intervals, I don't need absolute time, just relative
 * time between sensor readings, so this will suffice
 */
uint32_t get_cycle_count()
{
    return k_cycle_get_32();
}


//read value from the register passed in
uint8_t read_control_register(uint8_t offset)
{
    //set the address to be read as first byte of buffer
    acc_buffer[0] = offset;
    
    //write that to the i2c
    int err = i2c_write(i2c_dev, acc_buffer, 1, IMU_ADDRESS);
    if (err < 0)
    {
        printk("control register write failed: %d\n", err);
    }

    //read the byte from the i2c device
    err = i2c_read(i2c_dev, acc_buffer, 1, IMU_ADDRESS);
    if (err < 0)
    {
        printk("control register read failed: %d\n", err);
    }

    //convert to individual variable and return
    uint8_t controlRegisterValue = (uint8_t)acc_buffer[0];

    return controlRegisterValue;
}

//write data to the register specified
void write_control_register(uint8_t offset, uint8_t dataToWrite)
{
    //first slot gets the register to write
    acc_buffer[0] = offset;
    //second slot gets the data
    acc_buffer[1] = dataToWrite;

    //write 2 bytes to the i2c device
    int err = i2c_write(i2c_dev, acc_buffer, 2, IMU_ADDRESS);
    if (err < 0)
    {
        printk("control register write failed: %d\n", err);
    }
}



/********************* Bluetooth Code  *****************/
void bt_ready(int err)
{
	if (err)
	{
		printk("bt enable returns %d", err);
	}

	printk("bt_ready!\n");
	ble_ready = true;
}

int init_ble(void)
{
    int err;

    err = bt_enable(bt_ready);

    if (err)
    {
        printk("Also an error");
        printk("bt_enable failed (err %d)", err);
        return err;
    }

    return 0;
}

static int notify_adc(IMUData data)
{
    //used to calculate the length needed to create the buffer
    int len = snprintf(NULL, 0, "%f,%f,%f;%f,%f,%f;%" PRIu32,
        data.aData.AccX,
        data.aData.AccX,
        data.aData.AccZ,
        data.gData.GyroX,
        data.gData.GyroY,
        data.gData.GyroZ,
        data.cycleCount);

    //Different number of floats led to different values here than I would expect
    //need to dig optimizing this
    char buffer[len];
    snprintf(buffer, sizeof buffer, "%f,%f,%f;%f,%f,%f;%" PRIu32,
        data.aData.AccX,
        data.aData.AccY,
        data.aData.AccZ,
        data.gData.GyroX,
        data.gData.GyroY,
        data.gData.GyroZ,
        data.cycleCount);

    int rc;
    rc = bt_gatt_notify(NULL, &custom_srv.attrs[2], &buffer, sizeof(buffer));

    return rc == -ENOTCONN ? 0 : rc;
}

/*
* Callback to run whenever a bluetooth connection occurs
*/
static void connected(struct bt_conn *conn, uint8_t conn_err)
{
    printk("connected\n");
    ble_connected = true;
    operation_mode = THROW;
}

/*
* Callback to run whenever a bluetooth disconnection occurs
*/
static void disconnected(struct bt_conn *conn, uint8_t reason)
{
    printk("disconnected\n");
    ble_connected = false;
}

BT_CONN_CB_DEFINE(conn_callbacks) = {
	.connected = connected,
	.disconnected = disconnected
};
/******* /Bluetooth Code ********/


/********************* Sensor Code  *****************/

//configure IMU to specified settings
//sets the IMU control registers based on based in values
void configure_imu(IMUSettings settings)
{
    uint8_t dataToWrite = 0;

    //configuring accelerometer
    //each of these settings is stored in different bits of the register
    //so can OR them each individually and they'll set the correct bits
    //The LSM6DS3_ACC_GYRO_CTRL1_XL register is configured as follows:
    //first 4 bits:sampleRate
    //next 2 bits: scale
    //next 2 bits: bandwidth
    //this is reading left to right from the datasheet
    //Right now don't quite know which bit is MSB and LSB.
    dataToWrite |= settings.accBandwidth;
    dataToWrite |= settings.accScale;
    dataToWrite |= settings.accSampleRate;

    //write accelerometer config to register
    write_control_register(LSM6DS3_ACC_GYRO_CTRL1_XL, dataToWrite);

    //might still need to worry about the CTRL4_C register, not 100% sure at this point.

    //reset
    dataToWrite = 0;

    //configuring gyroscope
    //much like the accerelometer, each of these settings is stored
    //in different bits of the register. So we can OR them and they'll
    //set the correct bits.
    //The LSM6DS3_ACC_GYRO_CTRL2_G register is configured as follows
    //first 4 bits: sampleRate
    //next 2 bits: scale
    //next 1 bit: fullScale (really continuation of scale I believe)
    //last bit: 0 (never changes)
    //again, not 100% sure which bit is MSB and LSB
    dataToWrite |= settings.gyroFullScale;
    dataToWrite |= settings.gyroScale;
    dataToWrite |= settings.gyroSampleRate;

    //write gyro to register
    //TODO: This control register also controls the rotation scale, will do this later
    write_control_register(LSM6DS3_ACC_GYRO_CTRL2_G, dataToWrite);

    //reset
    dataToWrite = 0;
}

//uses IMUSettings to turn raw sensor values into correct values
AcceloremeterData calibrate_raw_accelerometer_values(IMUSettings settings, uint8_t startingIndex)
{
    float constant = 0.061;
    int scale = 1;
    switch (settings.accScale)
    {
        case ACC_SCALE_2G:
            scale = 0;
            break;
        case ACC_SCALE_4G:
            scale = 1;
            break;
        case ACC_SCALE_8G:
            scale = 2;
            break;
        case ACC_SCALE_16G:
            scale = 3;
            break;
    }

    float scaledConstant = constant * (1 << scale);

    //parse out different values from 6 byte buffer
    int16_t xOutput = (int16_t)acc_buffer[startingIndex + 0] | (int16_t)(acc_buffer[startingIndex + 1] << 8);
    int16_t yOutput = (int16_t)acc_buffer[startingIndex + 2] | (int16_t)(acc_buffer[startingIndex + 3] << 8);
    int16_t zOutput = (int16_t)acc_buffer[startingIndex + 4] | (int16_t)(acc_buffer[startingIndex + 5] << 8);

    float accX = (float)xOutput * scaledConstant / 1000;
    float accY = (float)yOutput * scaledConstant / 1000;
    float accZ = (float)zOutput * scaledConstant / 1000;

    struct AcceloremeterData data;
    data.AccX = accX;
    data.AccY = accY;
    data.AccZ = accZ;


    return data;
}

//take raw gyro inputs and output calibrated values
GyroData calibrate_raw_gyro_values(IMUSettings settings, uint8_t startingIndex)
{
    int scale = 1;
    switch (settings.gyroScale)
    {
        //Don't have 125dps, probably won't need it for this project
        // case GYRO_SCALE_250dps:
        //     scale = 0;
        //     break;
        case GYRO_SCALE_250dps:
            scale = 250;
            break;
        case GYRO_SCALE_500dps:
            scale = 500;
            break;
        case GYRO_SCALE_1000dps:
            scale = 1000;
            break;
        case GYRO_SCALE_2000dps:
            scale = 2000;
            break;
    }
    uint8_t gyroRangeDivisor = scale / 125;

    int16_t xOutput = (int16_t)acc_buffer[startingIndex + 0] | (int16_t)(acc_buffer[startingIndex + 1] << 8);
    int16_t yOutput = (int16_t)acc_buffer[startingIndex + 2] | (int16_t)(acc_buffer[startingIndex + 3] << 8);
    int16_t zOutput = (int16_t)acc_buffer[startingIndex + 4] | (int16_t)(acc_buffer[startingIndex + 5] << 8);
    
    float gyroX = (float)xOutput * 4.375 * (gyroRangeDivisor) / 1000;
    float gyroY = (float)yOutput * 4.375 * (gyroRangeDivisor) / 1000;
    float gyroZ = (float)zOutput * 4.375 * (gyroRangeDivisor) / 1000;

    struct GyroData data;
    data.GyroX = gyroX;
    data.GyroY = gyroY;
    data.GyroZ = gyroZ;

    return data;
}

//uses settings to read both the Gyro and accelerometer data from the IMU
IMUData pull_imu_data(IMUSettings settings)
{
    int err;
    acc_buffer[0] = LSM6DS3_ACC_GYRO_OUTX_L_G;

    //write the X value register to device
    err = i2c_write(i2c_dev, acc_buffer, 1, IMU_ADDRESS);
    if (err < 0)
    {
        printk("write failed: %d\n", err);
    }

    //read both gyro and accelerometer sensor data from registers
    //first 6 bytes are gyro, second 6 bytesa re acceleremeter
    err = i2c_read(i2c_dev, acc_buffer, 12, IMU_ADDRESS);
    if (err < 0)
    {
        printk("read failed: %d\n", err);
    }
    //place as close as I can to actual interaction with my IMU
    //not sure if placing it before might be more accurate
    uint32_t cycle_count = get_cycle_count();

    //get gyro data
    struct GyroData gdata = calibrate_raw_gyro_values(settings, 0);
    struct AcceloremeterData adata = calibrate_raw_accelerometer_values(settings, 6);

    struct IMUData imuData;
    imuData.gData = gdata;
    imuData.aData = adata;
    imuData.cycleCount = cycle_count;

    return imuData;
}

int main(void)
{
    //double check that device is ready
    if (!device_is_ready(i2c_dev))
    {
        printk("i2c_dev not ready\n");
        return 0;
    }

    init_ble();

    while (!ble_ready)
    {
        printk("BLE stack not ready yet\n");
        k_msleep(100);
    }
    printk("BLE stack ready\n");

    operation_mode = THROW;

    int err;
    err = bt_le_adv_start(BT_LE_ADV_CONN_NAME, ad, ARRAY_SIZE(ad), NULL, 0);
    if (err)
    {
        printk("Advertising failed to start (err %d)\n", err);
        return 1;
    }

    struct IMUSettings settings;
    settings.accSampleRate = ACC_SR_13330Hz;
    settings.accScale = ACC_SCALE_4G;
    settings.accBandwidth = ACC_BANDWIDTH_50HZ;
    settings.gyroSampleRate = GYRO_SR_1660Hz;
    settings.gyroScale = GYRO_SCALE_250dps;
    settings.gyroFullScale = GYRO_FULLSCALE_125dps_DISABLED;

    configure_imu(settings);

    int count = 0;

    while (true)
    {
        if (ble_connected)
        {
            if (operation_mode == THROW)
            {
                struct IMUData imuData = pull_imu_data(settings);

                //printk("%d: Writing to bluetooth service\n", count);
                err = notify_adc(imuData);
                if (err)
                {
                    printk("Writing failed (err %d)\n", err);
                    return 1;
                }
                count++;

                k_msleep(THROW_SLEEP_TIME_MS);
            }
            else if (operation_mode == CONFIG)
            {
                struct IMUData imuData = pull_imu_data(settings);

                //printk("%d: Writing to bluetooth service\n", count);
                err = notify_adc(imuData);
                if (err)
                {
                    printk("Writing failed (err %d)\n", err);
                    return 1;
                }
                count++;

                k_msleep(CONFIG_SLEEP_TIME_MS);
            }
        }
        else
        {
            k_msleep(UNCONNECTED_SLEEP_TIME_MS);
        }
    }
    return 0;
}

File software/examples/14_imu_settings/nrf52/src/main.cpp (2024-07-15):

/*****************************************************************************/
//Ensure values received from the IMU sensor are calibrated correctly
/*******************************************************************************/

#include "Arduino.h"
#include "LSM6DS3.h"
#include "Wire.h"

//Create a instance of class LSM6DS3
LSM6DS3 myIMU(I2C_MODE, 0x6A);    //I2C device address 0x6A


SensorSettings CreateSettings()
{
    SensorSettings settings = SensorSettings();
    //copied from Seeed library
    //https://github.com/Seeed-Studio/Seeed_Arduino_LSM6DS3/blob/master/LSM6DS3.cpp#L354
    settings.gyroEnabled = 1;  //Can be 0 or 1

    settings.gyroRange = 2000;   //Max deg/s.  Can be: 125, 245, 500, 1000, 2000
    settings.gyroSampleRate = 416;   //Hz.  Can be: 13, 26, 52, 104, 208, 416, 833, 1666
    settings.gyroBandWidth = 400;  //Hz.  Can be: 50, 100, 200, 400;
    settings.gyroFifoEnabled = 1;  //Set to include gyro in FIFO
    settings.gyroFifoDecimation = 1;  //set 1 for on /1

    settings.accelEnabled = 1;
    settings.accelODROff = 1;
    settings.accelRange = 16;      //Max G force readable.  Can be: 2, 4, 8, 16
    settings.accelSampleRate = 416;  //Hz.  Can be: 13, 26, 52, 104, 208, 416, 833, 1666, 3332, 6664, 13330
    settings.accelBandWidth = 100;  //Hz.  Can be: 50, 100, 200, 400;
    settings.accelFifoEnabled = 1;  //Set to include accelerometer in the FIFO
    settings.accelFifoDecimation = 1;  //set 1 for on /1

    settings.tempEnabled = 0;

    //Select interface mode
    settings.commMode = 1;  //Can be modes 1, 2 or 3

    //FIFO control data
    settings.fifoThreshold = 3000;  //Can be 0 to 4096 (16 bit bytes)
    settings.fifoSampleRate = 10;  //default 10Hz
    settings.fifoModeWord = 0;  //Default off

    return settings;
}

void setup() {
    // put your setup code here, to run once:
    Serial.begin(115200);
    while (!Serial);
    //Call .begin() to configure the IMUs
    if (myIMU.begin() != 0) {
        Serial.println("Device error");
    } else {
        Serial.println("Device OK!");
    }

    myIMU.settings = CreateSettings();
}

void loop() {
    //Accelerometer
    float accX = myIMU.readFloatAccelX();
    float accY = myIMU.readFloatAccelY();
    float accZ = myIMU.readFloatAccelZ();
    Serial.print("Accelerometer:");
    Serial.print(" X = ");
    Serial.print(accX, 4);

    Serial.print(", Y = ");
    Serial.print(accY, 4);

    Serial.print(", Z = ");
    Serial.println(accZ, 4);

    //Gyroscope
    float gyroX = myIMU.readFloatGyroX();
    float gyroY = myIMU.readFloatGyroY();
    float gyroZ = myIMU.readFloatGyroZ();
    Serial.print("Gyroscope:");
    Serial.print(" X = ");
    Serial.print(gyroX, 4);

    Serial.print(", Y = ");
    Serial.print(gyroY, 4);

    Serial.print(", Z = ");
    Serial.println(gyroZ, 4);

    delay(1000);
}

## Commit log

2024-05-25 Adding esp32 to esp32 bluetooth example, cleaning up the example
2024-05-25 Adding initial code and readme for esp32 to windows bluetooth connection
2024-05-26 Got notifications flowing from esp32 to windows, still work to do
2024-06-04 Laying groundwork for platformIO project to begin monitoring accelerometer readings
2024-06-05 Able to receive messages from esp32 in csharp
2024-06-06 working 08 example before all the accelerometer code
2024-06-08 Working example of pushing accelerometer data to computer
2024-06-08 Cleaning up esp32 code
2024-06-24 Fixing small bug with disconnection
    [main.cpp]
2024-06-25 Adding code to calibrate gyro
2024-06-25 Adding stuff for accelerometer angles
2024-06-25 Adding code for measuring angles using Accelerometer
2024-06-26 Adding link to high performance sensors
2024-06-28 Adding links to schematics
2024-06-30 Adding notes from sensors
2024-07-11 Adding hardware examples for nrf52Sense
    [XiaoSensePcb.kicad_pcb, XiaoSensePcb.kicad_sch]
2024-07-11 Adding example 12, accelerometer on the sense
2024-07-11 working on sense imu from platformio
2024-07-15 Updating code based on arduino example
2024-07-15 Adding platformIO example for builtin IMU
2024-07-16 Rolling back comments after fixing serial startup wait issue
    [main.cpp]
2024-07-17 Adding kicad files for xiao sense pcb board
    [XiaoSensePcb-B_Cu.gbr, XiaoSensePcb-B_Mask.gbr, XiaoSensePcb-B_Paste.gbr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]
2024-07-21 Adding last files for xiao sense pcb
2024-07-21 Adding some more info to the PCB design example
2024-07-21 Adding 02 putter housing
2024-07-22 Adding first Avalonian application, working through the sample tutorial
2024-07-24 Adding 3d design for putting housing
2024-07-31 Adding the ability to scan for bluetooth devices nearby
2024-08-06 Adding the ability to display messages from bluetooth sensor on home page
2024-08-26 Changing to sending accelerometer and gyro data at different times
2024-08-28 Adding the ability to create sqlite database to track data
2024-09-08 Starting using channels to write sensor data to db
2024-09-09 Writing sensor data to database
2024-09-09 Moving sensor data to models namespace
2024-09-10 Using enum to track page state
2024-09-10 Adding a state to track bluetooth connection status
2024-09-17 Adding blink example for xiao sense board
2024-09-20 Adding basic battery bluetooth service
2024-10-01 Adding some notes on the xiao sense imu
2024-10-01 Starting work on reading values from the IMU sensor
2024-10-01 Adding more code for temperature calculation
2024-10-02 Adding the ability to read from register and calculate temperature
2024-10-03 Correcting i2c device address
    [main.c]
2024-10-04 Adding temperature sensing code, still need to clean it up
2024-10-05 Adding the start of configuring the IMU sensor
2024-10-06 Rounding out the accelerometer configuration for CTRL1_XL register
2024-10-06 Adding gyro configuration
2024-10-06 First time reading accelometer sensor data
2024-10-06 Working on getting all accelerometer values, still got some debugging to do
2024-10-06 Correcting which buffer is being read from.
    [main.c]
2024-10-07 Fixing the accelerometer scaling problem
    [main.c]
2024-10-07 Adding calculation for gyro values
2024-10-07 Adding final code changes to this example, printing out both acc and gyro data
2024-10-09 Upping bluetooth message size, pushing accelerometer values over bluetooth
2024-10-09 Sending gyro data across bluetooth as well
2024-10-10 Fixing client to save all 6 data points at once
    [main.c]
2024-10-17 Adding the ability to disconnect from a bluetooth device
2024-10-17 Allowing token to be cancelled if device disconnects, still some bugs
2024-10-18 Fixing reconnecting to bluetooth device after device loses power
2024-10-23 Trying to write to bluetooth device
2024-10-23 Fixing the write response issue
    [main.c]
2024-10-28 Extracting out receiving sensor readings
2024-10-28 Displaying sensor data in configuration
2024-11-01 Graphing 2 dimensions of sensor data
